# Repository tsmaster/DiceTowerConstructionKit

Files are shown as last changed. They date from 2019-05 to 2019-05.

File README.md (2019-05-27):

# Modular Dice Tower Construction Kit

By Dave LeCompte

https://github.com/tsmaster/DiceTowerConstructionKit
https://www.thingiverse.com/thing:3640800

I recently got a Monoprice Mini Delta 3D printer, which has a 110mm
diameter print bed. This is adequate for a lot of printing jobs, but
can provide an interesting constraint for larger tasks. I wanted to
try to make a dice tower that would fit inside the print volume.

This project is a collection of modules, largely printable on a small
printer, that can be assembled in a variety of ways, to provide
customizable randomization for your dice rolls.

Current modules include:

 - Conical Funnel: a cone-shaped funnel that might be at the top, where you might put the dice in

 - Spacer: a "null" module that doesn't interfere with the dice, just gives them room to fall

 - Triangular beam: a beam across the module with a triangular cross section, bouncing some one way, some the other way

 - Receiver: a module to put at the bottom to collect the dice.

 - Ramp: a simple 45 degree slat that bounces dice away from one edge of a tube

 - Chain: a tube with a chain spanning the center

 - Propellor: a pair of blades that cause the dice to go counterclockwise around the tube

 - Spiral Staircase: a spiral staircase, suitable for tiny wizards to climb

 - "The Juicer": dice come in, random juice goes out. (Really, just a 6-way funnel.)

More modules are planned. You can print out any number of modules and
assemble them as you like, and each module can be freely
rotated. Maybe you want to roll some dice at the beginning of a
session to decide which modules, and in which order, to assemble into
your custom tower. Or, maybe you just got a critical failure and need
to get a better randomization stream for future die rolls - just
reassemble the tower at the table; quick and easy!

## Software Required

If you want to just print out the files I've built, nothing special is
required. However, if you want to contribute, it's good to know I'm
using an unusual pipeline:

### Python3

I've been a holdout and have been using Python2 for years. It's
finally time for me to get comfortable with Python3. The scripts
*probably* work with Python2, but I'm not going to maintain that.

### OpenPySCAD

https://github.com/taxpon/openpyscad

A Python-to-OpenSCAD library. Seems to do what I need. I'm familiar
with Python's imperative programming style, so writing in Python is
easier for my brain.

### OpenSCAD

https://www.openscad.org/

Converts the .scad files into .stl files. After that, you're off to
the races.

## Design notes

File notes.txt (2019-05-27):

a quarter sphere shell as a simple approach to a dice tower

a cylinder around the base as a "corral"

random holes and bumps to make the dice tumble unpredictably

----------

New! Modular Stackable Stovepipe Design

with a rim rail mounting, can assemble a bunch of modules to make a new tower each time.

Modules:

[x] Larger base (non circle)

[x] Ramp - an inclined plane on one (2?) sides of the tube

[x] Propellor - an inclined plane pushing dice tangentially

[ ] Beam - just a simple strut across a radius (chord?)
  
  [x] triangular cross section

  [ ] semicircle (for Darryl)

  [ ] louver
  
[ ] Funnel - push the dice toward the center

  [X] Cone Funnel - funnel with a circular hole

  [ ] polygon funnel - funnel with a parametric number of sides

  [ ] torus funnel - funnel made from a torus

  [ ] particle vortex funnel - funnel made by carving particle paths out of a solid

[ ] Offset Funnel - as above, but offset

[ ] funnel with "net" mesh funnel

[ ] Curvy Blade - like a beam, but with a concave up cross section across the blade, concave down along the blade

[x] juicer - like an orange juicer, but dice come out, not juice

[x] chain - a tube with a print-in-place chain across the tube

[X] null tube - just a tube

[ ] receiver - corral section, deflector ramp

  [X] ramp rcv - flat deflector

  [ ] rcv with sphere deflector

  [ ] rcv with scoop (cylinder) deflector

[ ] tube with internal screws (like the inside of a nut)

[x] spiral staircase

[ ] through-holes for chopsticks / pencils 

[ ] decorative inside

  [ ] pit of hands, like in Labyrinth

  [ ] pit of faces

  [ ] pit of fiddles

[ ] decorative outside

  [ ] looking like a stained glass window, flying buttresses

  [ ] hexagons, regular

  [ ] hexagons, scattered (random?)

  [ ] procedural (blue noise) circular holes

  [ ] diamonds

---

TODO (May 26, 2019)

There are several things I want to fix, now that I've printed about 10
modules.

The big one is restricting the contents of tubes to not extend into
the top "rim" area, as this makes it difficult to stack modules. It
may also make it difficult for dice to pass from module to module, but
that's a lesser concern, and can to some degree be handled by the user
at the table.

Other notes of fixes:

[x] make funnel mouth larger

[x] make funnel wall thinner

[x] make chain an even number of links so the anchors don't both face the same way.

[x] add central pillar to spiral staircase

[x] re-export all modules with the rim non-encroachment

  [x] beam

  [x] chain

  [x] funnel

  [x] propellor

  [x] ramp

  [x] spiral staircase

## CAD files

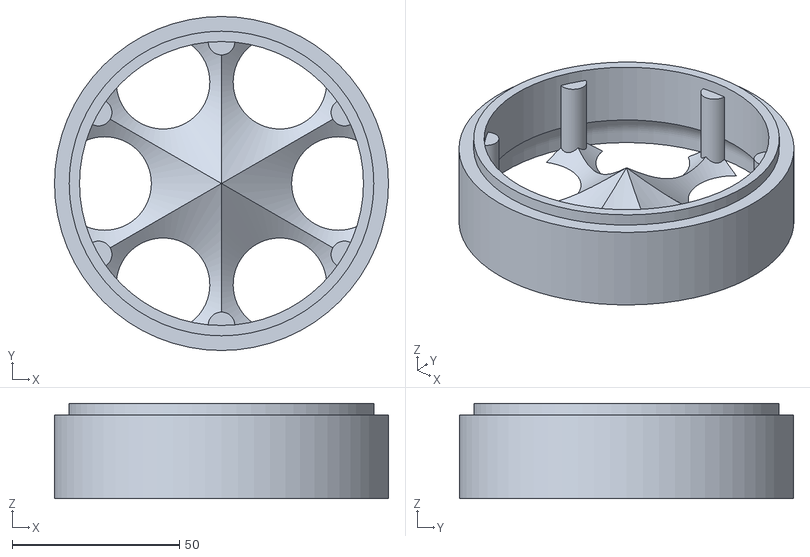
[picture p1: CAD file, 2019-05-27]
Stl/juicer.stl
100.0 x 100.0 x 28.5

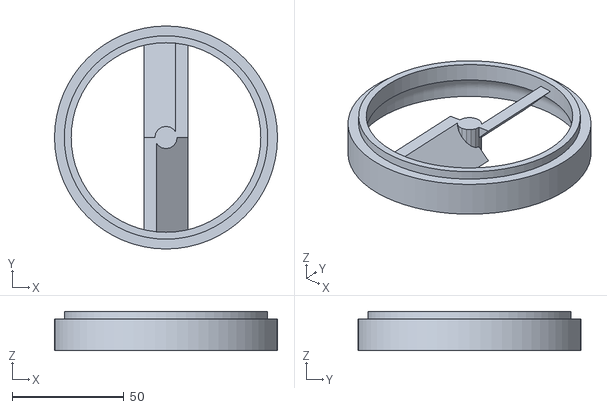
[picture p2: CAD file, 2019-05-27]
Stl/propellor.stl
100.0 x 100.0 x 17.6

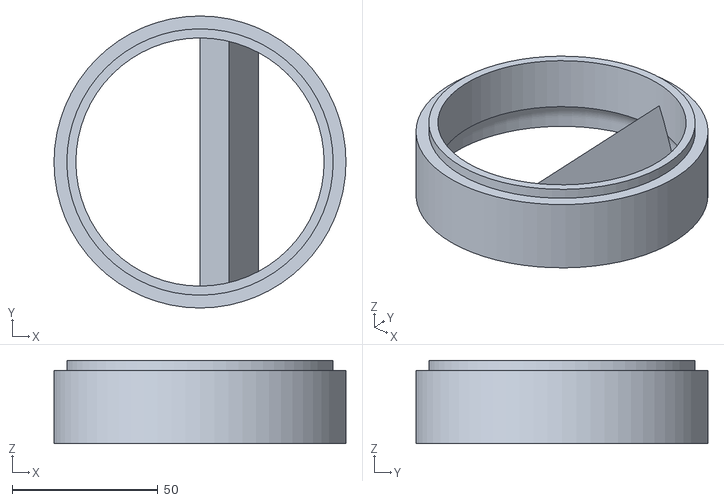
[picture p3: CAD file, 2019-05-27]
Stl/beam2.stl
100.0 x 100.0 x 28.5

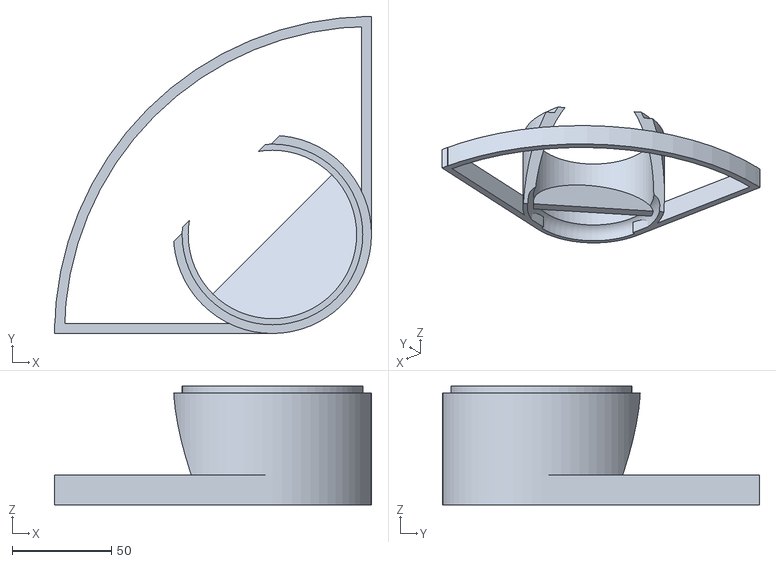
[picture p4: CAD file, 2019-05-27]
Stl/coll_lg.stl
160.0 x 160.0 x 60.0

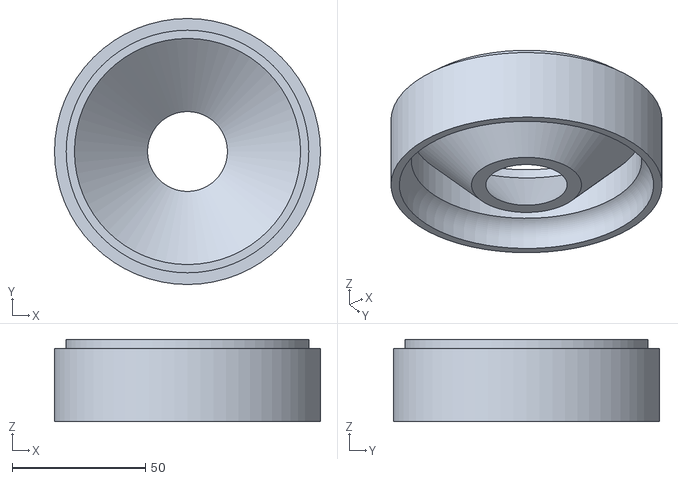
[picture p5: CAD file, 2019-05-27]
Stl/coneFunnel.stl
100.0 x 100.0 x 31.0

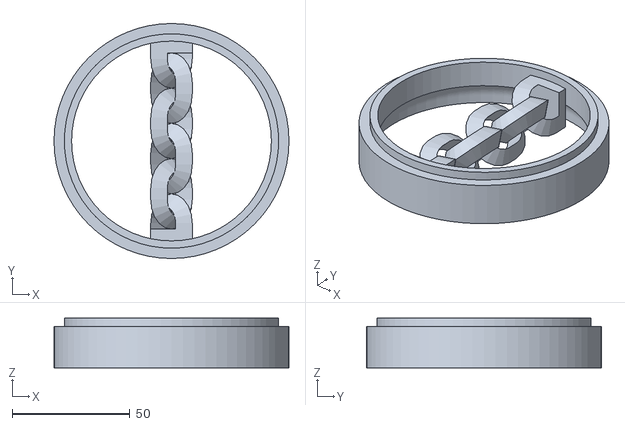
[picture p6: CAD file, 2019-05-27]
Stl/chain.stl
100.0 x 100.0 x 21.2

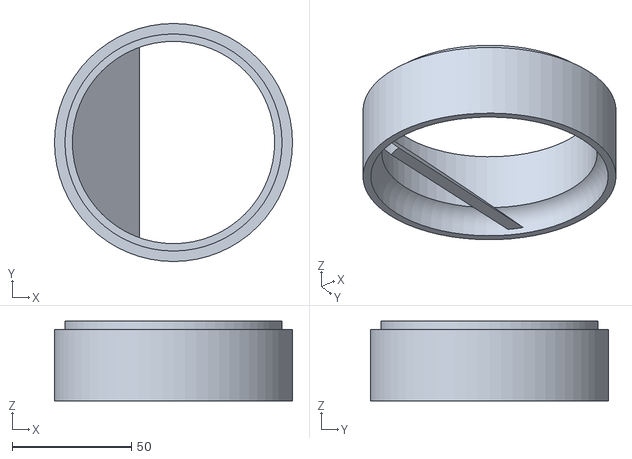
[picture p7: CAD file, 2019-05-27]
Stl/ramp1.stl
100.0 x 100.0 x 33.5

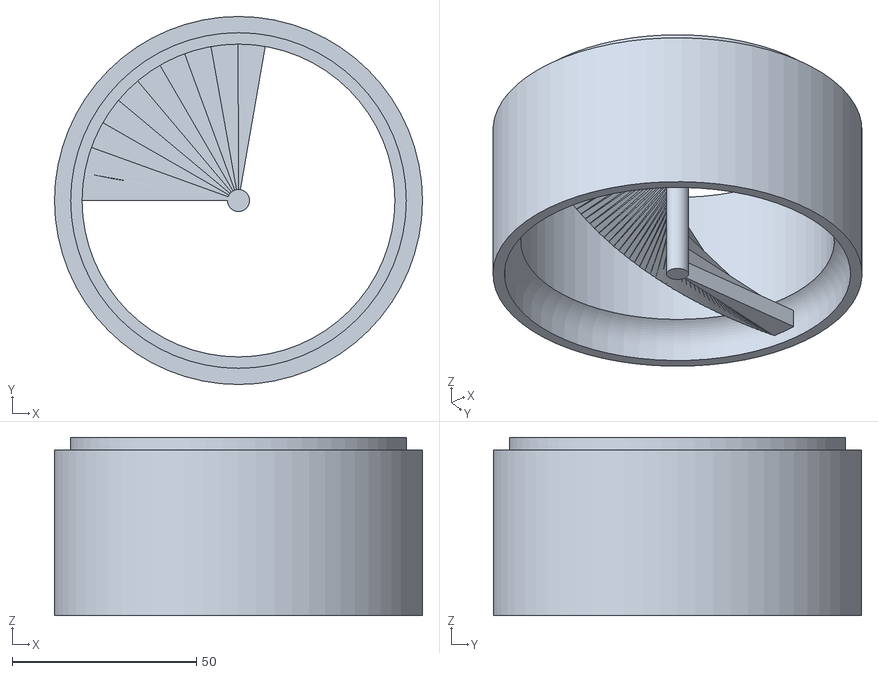
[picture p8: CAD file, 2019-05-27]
Stl/staircase.stl
100.0 x 100.0 x 48.5

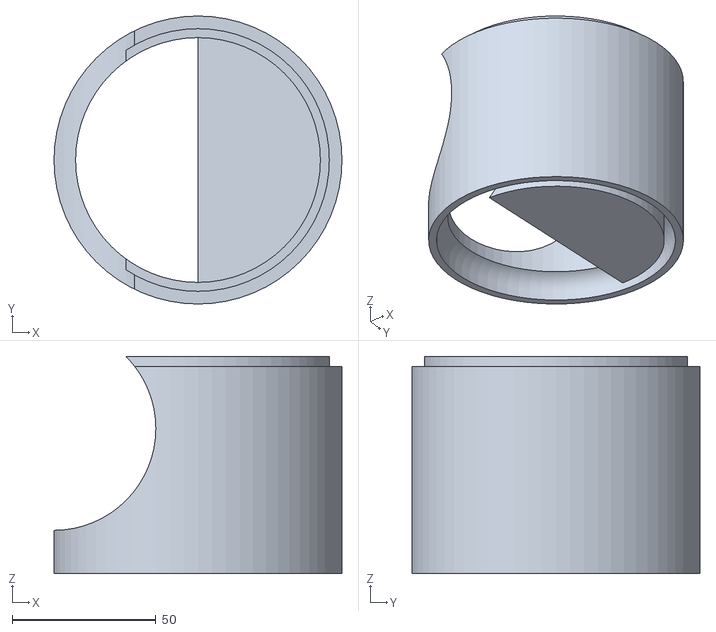
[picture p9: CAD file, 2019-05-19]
Stl/collector.stl
100.0 x 100.0 x 75.4

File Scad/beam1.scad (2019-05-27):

union(){
    difference(){
        cylinder(h=28.5, r=50.0, $fn=64);
        translate(v=[0, 0, -12.5]){
            cylinder(h=50, r=42.5, $fn=64);
        };
        union(){
            translate(v=[0, 0, -1]){
                cylinder(h=4.5, r=46.9, $fn=64);
            };
            translate(v=[0, 0, 3.5]){
                rotate_extrude(convexity=10, $fn=64){
                    translate(v=[39.4, 0, 0]){
                        circle(r=7.5, $fn=64);
                    };
                };
            };
        };
        translate(v=[0, 0, 25]){
            difference(){
                cylinder(h=4.5, r=51.0, $fn=64);
                translate(v=[0, 0, -1]){
                    cylinder(h=5.5, r=45.6, $fn=64);
                };
            };
        };
    };
    intersection(){
        translate(v=[5, 0, 0]){
            rotate(a=[90, 0, 0]){
                translate(v=[0, 0, -50.0]){
                    linear_extrude(height=100){
                        polygon(points=[[-10, 0], [10, 0], [0, 20]]);
                    };
                };
            };
        };
        cylinder(h=25, r=42.5, $fn=64);
    };
};

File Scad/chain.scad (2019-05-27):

union(){
    difference(){
        cylinder(h=21.17766952966369, r=50.0, $fn=64);
        translate(v=[0, 0, -8.838834764831844]){
            cylinder(h=35.35533905932738, r=42.5, $fn=64);
        };
        union(){
            translate(v=[0, 0, -1]){
                cylinder(h=4.5, r=46.9, $fn=64);
            };
            translate(v=[0, 0, 3.5]){
                rotate_extrude(convexity=10, $fn=64){
                    translate(v=[39.4, 0, 0]){
                        circle(r=7.5, $fn=64);
                    };
                };
            };
        };
        translate(v=[0, 0, 17.67766952966369]){
            difference(){
                cylinder(h=4.5, r=51.0, $fn=64);
                translate(v=[0, 0, -1]){
                    cylinder(h=5.5, r=45.6, $fn=64);
                };
            };
        };
    };
    intersection(){
        union(){
            translate(v=[0, -52.5, 0]){
                union(){
                    translate(v=[0, 30.0, 0]){
                        translate(v=[0, 0, 8.838834764831844]){
                            rotate(a=[0, 45, 0]){
                                union(){
                                    translate(v=[7.5, 2.5, 0]){
                                        rotate(a=[90, 0, 0]){
                                            linear_extrude(height=5.0){
                                                polygon(points=[[0, -5], [0, 5], [5, 0]]);
                                            };
                                        };
                                    };
                                    rotate(a=[0, 0, 180]){
                                        translate(v=[7.5, 2.5, 0]){
                                            rotate(a=[90, 0, 0]){
                                                linear_extrude(height=5.0){
                                                    polygon(points=[[0, -5], [0, 5], [5, 0]]);
                                                };
                                            };
                                        };
                                    };
                                    translate(v=[0, 2.5, 0]){
                                        rotate_extrude(angle=180, convexity=10, $fn=20){
                                            translate(v=[7.5, 0]){
                                                polygon(points=[[0, -5], [0, 5], [5, 0]]);
                                            };
                                        };
                                    };
                                    rotate(a=[0, 0, 180]){
                                        translate(v=[0, 2.5, 0]){
                                            rotate_extrude(angle=180, convexity=10, $fn=20){
                                                translate(v=[7.5, 0]){
                                                    polygon(points=[[0, -5], [0, 5], [5, 0]]);
                                                };
                                            };
                                        };
                                    };
                                };
                            };
                        };
                    };
                    translate(v=[0, 15.0, 0]){
                        translate(v=[0, 0, 8.838834764831844]){
                            rotate(a=[0, -45, 0]){
                                union(){
                                    translate(v=[7.5, 2.5, 0]){
                                        rotate(a=[90, 0, 0]){
                                            linear_extrude(height=5.0){
                                                polygon(points=[[0, -5], [0, 5], [5, 0]]);
                                            };
                                        };
                                    };
                                    rotate(a=[0, 0, 180]){
                                        translate(v=[7.5, 2.5, 0]){
                                            rotate(a=[90, 0, 0]){
                                                linear_extrude(height=5.0){
                                                    polygon(points=[[0, -5], [0, 5], [5, 0]]);
                                                };
                                            };
                                        };
                                    };
                                    translate(v=[0, 2.5, 0]){
                                        rotate_extrude(angle=180, convexity=10, $fn=20){
                                            translate(v=[7.5, 0]){
                                                polygon(points=[[0, -5], [0, 5], [5, 0]]);
                                            };
                                        };
                                    };
                                    rotate(a=[0, 0, 180]){
                                        translate(v=[0, 2.5, 0]){
                                            rotate_extrude(angle=180, convexity=10, $fn=20){
                                                translate(v=[7.5, 0]){
                                                    polygon(points=[[0, -5], [0, 5], [5, 0]]);
                                                };
                                            };
                                        };
                                    };
                                };
                            };
                        };
                    };
                    translate(v=[0, 30.0, 0]){
                        union(){
                            translate(v=[0, 30.0, 0]){
                                translate(v=[0, 0, 8.838834764831844]){
                                    rotate(a=[0, 45, 0]){
                                        union(){
                                            translate(v=[7.5, 2.5, 0]){
                                                rotate(a=[90, 0, 0]){
                                                    linear_extrude(height=5.0){
                                                        polygon(points=[[0, -5], [0, 5], [5, 0]]);
                                                    };
                                                };
                                            };
                                            rotate(a=[0, 0, 180]){
                                                translate(v=[7.5, 2.5, 0]){
                                                    rotate(a=[90, 0, 0]){
                                                        linear_extrude(height=5.0){
                                                            polygon(points=[[0, -5], [0, 5], [5, 0]]);
                                                        };
                                                    };
                                                };
                                            };
                                            translate(v=[0, 2.5, 0]){
                                                rotate_extrude(angle=180, convexity=10, $fn=20){
                                                    translate(v=[7.5, 0]){
                                                        polygon(points=[[0, -5], [0, 5], [5, 0]]);
                                                    };
                                                };
                                            };
                                            rotate(a=[0, 0, 180]){
                                                translate(v=[0, 2.5, 0]){
                                                    rotate_extrude(angle=180, convexity=10, $fn=20){
                                                        translate(v=[7.5, 0]){
                                                            polygon(points=[[0, -5], [0, 5], [5, 0]]);
                                                        };
                                                    };
                                                };
                                            };
                                        };
                                    };
                                };
                            };
                            translate(v=[0, 15.0, 0]){
                                translate(v=[0, 0, 8.838834764831844]){
                                    rotate(a=[0, -45, 0]){
                                        union(){
                                            translate(v=[7.5, 2.5, 0]){
                                                rotate(a=[90, 0, 0]){
                                                    linear_extrude(height=5.0){
                                                        polygon(points=[[0, -5], [0, 5], [5, 0]]);
                                                    };
                                                };
                                            };
                                            rotate(a=[0, 0, 180]){
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

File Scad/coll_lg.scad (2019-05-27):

union(){
    difference(){
        cylinder(h=60.0, r=50.0, $fn=64);
        translate(v=[0, 0, -30.0]){
            cylinder(h=120.0, r=42.5, $fn=64);
        };
        union(){
            translate(v=[0, 0, -1]){
                cylinder(h=4.5, r=46.9, $fn=64);
            };
            translate(v=[0, 0, 3.5]){
                rotate_extrude(convexity=10, $fn=64){
                    translate(v=[39.4, 0, 0]){
                        circle(r=7.5, $fn=64);
                    };
                };
            };
        };
        translate(v=[0, 0, 56.5]){
            difference(){
                cylinder(h=4.5, r=51.0, $fn=64);
                translate(v=[0, 0, -1]){
                    cylinder(h=5.5, r=45.6, $fn=64);
                };
            };
        };
        rotate(a=[0, 0, 135]){
            rotate(a=[0, 30, 0]){
                translate(v=[0, -51.0, 0]){
                    cube(size=[51.0, 102, 120.0]);
                };
            };
        };
    };
    translate(v=[-110.0, -50.0, 0]){
        cube(size=[110.0, 5, 15.0]);
    };
    translate(v=[50.0, 0, 0]){
        rotate(a=[0, 0, 90]){
            cube(size=[110.0, 5, 15.0]);
        };
    };
    translate(v=[50.0, -50.0, 0]){
        intersection(){
            difference(){
                cylinder(h=15.0, r=160.0, $fn=64);
                translate(v=[0, 0, -1]){
                    cylinder(h=17.0, r=155.0, $fn=64);
                };
            };
            translate(v=[-161.0, 0, -1]){
                cube(size=[161.0, 161.0, 17.0]);
            };
        };
    };
    intersection(){
        rotate(a=[0, 0, -45]){
            rotate(a=[0, 45, 0]){
                translate(v=[0, -50.0, 0]){
                    cube(size=[5, 100, 100]);
                };
            };
        };
        cylinder(h=60.0, r=42.5, $fn=64);
    };
};

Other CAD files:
Stl/beam1.stl
Scad/beam2.scad
Scad/collector.scad
Scad/coneFunnel.scad
Scad/juicer.scad
Scad/propellor.scad
Scad/ramp1.scad
Scad/staircase.scad

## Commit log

2019-05-19 Added files.
    [beam.scad, beam1.scad, beam1.stl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]
2019-05-22 Added ramp module
    [ramp1.scad, ramp1.stl]
2019-05-22 Added chain module
    [chain.scad, chain.stl]
2019-05-22 Added an anchor on both sides of the chain for better solidity.
    [chain.scad, chain.stl]
2019-05-23 Added propellor
    [propellor.scad, propellor.stl]
2019-05-24 Added spiral staircase
    [staircase.scad, staircase.stl]
2019-05-24 Move Python into Src, SCAD into Scad, STL into Stl.
    [beam.scad, beam1.scad, beam1.stl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]
2019-05-27 refactored most models to respect top rim space tweaked funnel to have wider mouth, less wall width added central pillar to spiral staircase adjusted chain to be larger, have opposing anchors
    [beam.scad, beam1.scad, beam1.stl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]
2019-05-27 Added "The Juicer", a 6-way funnel
    [juicer.scad, juicer.stl]
